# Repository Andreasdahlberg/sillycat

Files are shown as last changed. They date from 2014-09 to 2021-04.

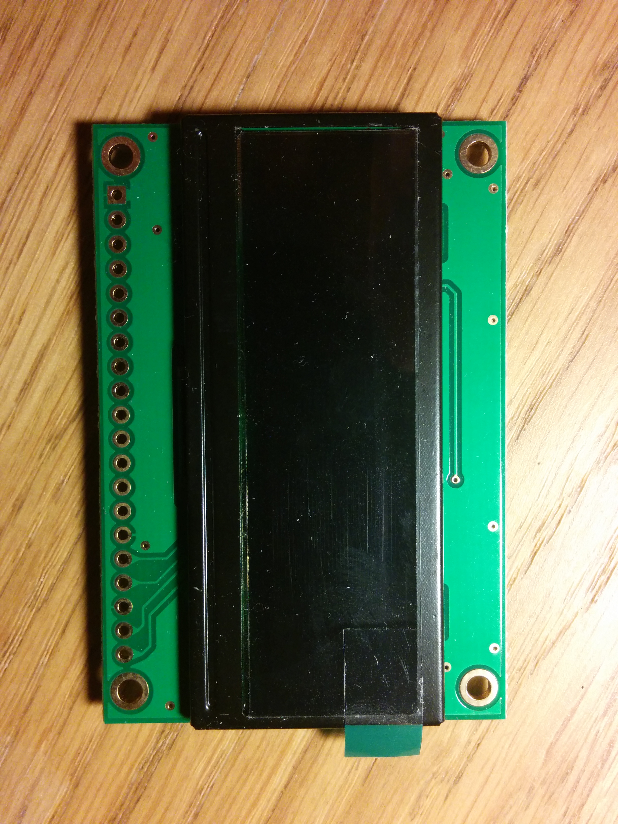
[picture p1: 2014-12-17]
hardware/main_unit_exterior/electrical_components/IMG_20141217_185025.jpg

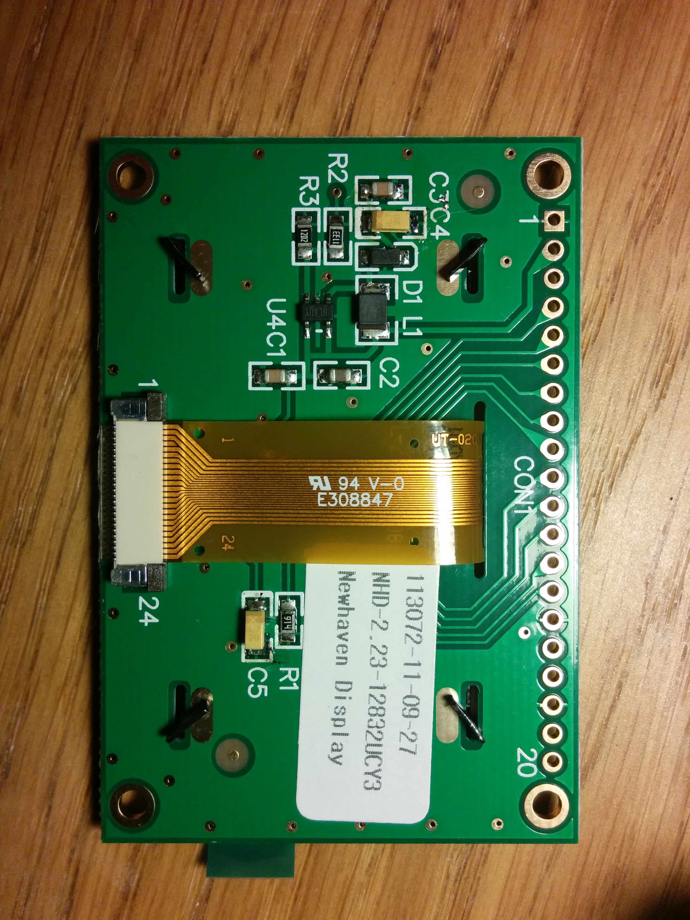
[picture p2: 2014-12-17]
hardware/main_unit_exterior/electrical_components/IMG_20141217_183510.jpg

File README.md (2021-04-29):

SillyCat
========




## Development

### Getting Started
The following steps are required

1. Install required packages
    ```bash
    $ sudo apt install scons gcc-avr avr-libc avrdude
    ```

1. Install optional packages
    ```bash
    $ sudo apt install astyle valgrind
    ```

1. Install [cmocka](https://cmocka.org/)
    ```bash
    $ sudo apt install cmake
    $ git clone git://git.cryptomilk.org/projects/cmocka.git
    $ mkdir cmocka/build && cd cmocka/build
    $ cmake -DCMAKE_INSTALL_PREFIX=/usr ..
    $ make
    $ sudo make install
    ```

1. Install [freetype-py](https://pypi.org/project/freetype-py/)
    ```bash
    $ sudo apt install python3-setuptools
    $ git clone https://github.com/rougier/freetype-py.git freetype-py
    $ cd freetype-py
    $ sudo python3 setup.py install
    ```

### Building
```bash
$ cd firmware
$ scons build-main-release build-node-release
```

### Board bringup
1. Set fuses
    ```bash
    $ scons init-fuses
    ```

1. Get configuration
    ```bash
    $ scripts/memory/config.py load /dev/ttyACM0 conf.eep
    ```

1. Set configuration values
    ```bash
    $ scripts/memory/config.py set conf.eep version 1
    $ scripts/memory/config.py set conf.eep network_id AABBCCDDEEFF
    $ scripts/memory/config.py set conf.eep aes_key 1DUMMYKEYFOOBAR1
    $ scripts/memory/config.py set conf.eep master_address 170
    $ scripts/memory/config.py set conf.eep address 170
    $ scripts/memory/config.py set conf.eep broadcast_address 255
    $ scripts/memory/config.py set conf.eep report_interval 60
    ```
    
    See [Configuration](scripts/memory/README.md#config) for details.

1. Save configuration to device
    ```bash
    $ /config.py save /dev/ttyACM0 conf.eep
    ```

1. Flash firmware
    ```bash
    scons flash-main-release
    ```   

### Testing
See [Testing](firmware/tests/README.md)

### CI
See [Docker](docker/README.md)

## Support
If you're having any problems, please raise an issue on GitHub and i will be happy to help.

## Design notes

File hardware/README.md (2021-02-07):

# Hardware description

## Main Unit

### BOM
| Qty | Line Item | Manufacturer | MPN | Octopart URL | Schematic Reference |
|-----|---|---|---|---|---|
| 1 | RFM69HW-868S2 | HOPERF | RFM69HW-868S2 | https://octopart.com/rfm69hw-868s2-hoperf-95997182 | U3 |
| 1 | 105133-0001 | Molex | 105133-0001 | https://octopart.com/105133-0001-molex-22605641 | U7 |
| 1 | NHD-2.23-12832UCY3 | Newhaven Display | NHD-2.23-12832UCY3 | https://octopart.com/nhd-2.23-12832ucy3-newhaven+display-20012478 | N/A |
| 1 | ATMEGA328P-AUR | Microchip | ATMEGA328P-AUR | https://octopart.com/atmega328p-aur-microchip-77760216 | U1 |
| 1 | CL21A106KPFNNNG | Samsung | CL21A106KPFNNNG | https://octopart.com/cl21a106kpfnnng-samsung-21703273 | C15 |
| 1 | CL21B103KAANNNC | Samsung | CL21B103KAANNNC | https://octopart.com/cl21b103kaannnc-samsung-19832247 | C4 |
| 5 | CL21B104KACNNNC | Samsung | CL21B104KACNNNC | https://octopart.com/cl21b104kacnnnc-samsung-19832262 | C1,C2,C7,C10,C12 |
| 6 | CL21B105KAFNNNE | Samsung | CL21B105KAFNNNE | https://octopart.com/cl21b105kafnnne-samsung-9301147 | C6,C8,C9,C11,C13,C14 |
| 1 | LD1117V33 | STMicroelectronics | LD1117V33 | https://octopart.com/ld1117v33-stmicroelectronics-526800 | U8 |
| 3 | RC2012J101CS | Samsung | RC2012J101CS | https://octopart.com/rc2012j101cs-samsung-63172 | R2,R3,R5 |
| 1 | RC2012F472CS | Samsung | RC2012F472CS | https://octopart.com/rc2012f472cs-samsung-26451238 | R1 |
| 1 | 22284200 | Molex | 22284200 | https://octopart.com/0022284200-molex-17769515 | U2 |
| 1 | 61200621621 | Würth Elektronik | 61200621621 | https://octopart.com/61200621621-w%C3%BCrth+elektronik-32855456 | U11 |
| 1 | BH32T-C | Memory Protection Devices | BH32T-C | https://octopart.com/bh32t-c-memory+protection+devices-30310562 | U5 |
| 10  | RC2012F103CS | Samsung | RC2012F103CS | https://octopart.com/rc2012f103cs-samsung-22085131 | R4,R6,R7,R8,R9,R10,R11,R12,R13,R14 |
| 1 | 22284040 | Molex | 22-28-4040 | https://octopart.com/22-28-4040-molex-278172 | J1,J4 |
| 1 | DS3234S# | Maxim Integrated | DS3234S# | https://octopart.com/ds3234s%23-maxim+integrated-8045298 | U9 |
| 1 | U.FL-R-SMT-1(40) | Hirose | U.FL-R-SMT-1(40) | https://octopart.com/u.fl-r-smt-1%2840%29-hirose-25525713 | J5 |

## Links
[Octopart BOM](https://octopart.com/bom-tool/Nu0NE4Zn)

[OSHPark PCB](https://oshpark.com/shared_projects/RTkTkiwv)

## Node Unit

## Gerbers
[NI Ultiboard](https://en.wikipedia.org/wiki/NI_Ultiboard) is used to generate the gerber files.

1. [Remove alignment points](https://docs.oshpark.com/design-tools/ni-ultiboard/removing-alignment-points/)
1. Click on File->Export and select the *Exports* tab
1. Check the Gerber RS-274X option and select the following layers:
	* Copper(all)
	* Board Outline
	* Silkscreen Top
	* Silkscreen Bottom
	* Solder Mask Top
	* Solder Mask Bottom
	* Drill(all)
1. Check the NC drill and select the following options:
	* Imperial
	* Coordinate format 2.4

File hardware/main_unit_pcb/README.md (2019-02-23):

# Main PCB

## Links
[BOM](https://octopart.com/bom-tool/QjR0VuVt)

[Order Rev1 PCB](https://oshpark.com/shared_projects/RTkTkiwv)

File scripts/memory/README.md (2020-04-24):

# Memory helper scripts

## Reader
Reader is a script for reading and printing device error logs. This can be done
directly from the device by dumping the EEPROM or by reading the EEPROM content
from a HEX-file.

### Usage
Read error log from device:
```bash
$ ./reader.py port <PORT>
```

Read error log from file:
```bash
$ ./reader.py file <FILENAME>
```

## Config
Config is a script used for configuration of both node and main devices.

### Usage
Load the configuration from the device into a configuration file:
```bash
$ ./config.py load <PORT> <FILENAME>
```

Print configuration values from the supplied configuration file:
```bash
$ ./config.py get <FILENAME> version address
version=1
address=170
```

Set a configuration value in the configuration file:
```bash
$ ./config.py set <FILENAME> address 128
```

Save the configuration file to device:
```bash
$ ./config.py save <PORT> <FILENAME>
```

## Hardware Requirements
When dumping the EEPROM from device an AVR programmer such as
[Olimex AVR-ISP-MK2](https://www.olimex.com/Products/AVR/Programmers/AVR-ISP-MK2/open-source-hardware)
is needed.

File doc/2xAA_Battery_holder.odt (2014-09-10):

PCB direct mounting AA battery holders

Description

A neat 2 x AA battery holder which can mount directly onto a PCB, thus saving ugly wiring and mounting problems.

Specifications

Dimensions: 57 mm x 33 mm x 15 mm

Battery: 2 x AA batteries

Connections: PCB pins on base (12 mm between pins)

Color: Black

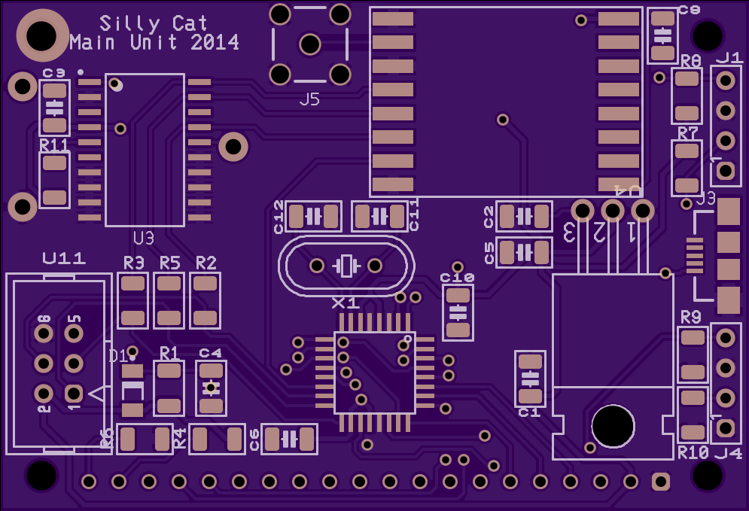
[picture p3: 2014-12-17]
hardware/main_unit_exterior/pcb_top.png

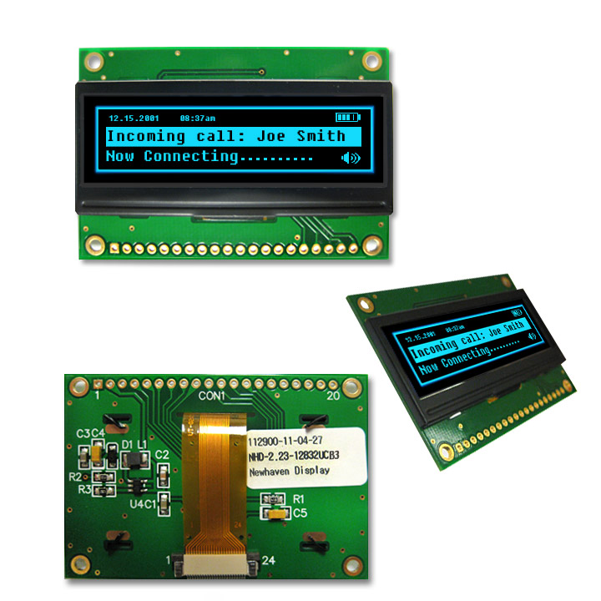
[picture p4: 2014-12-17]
hardware/main_unit_exterior/display.jpg

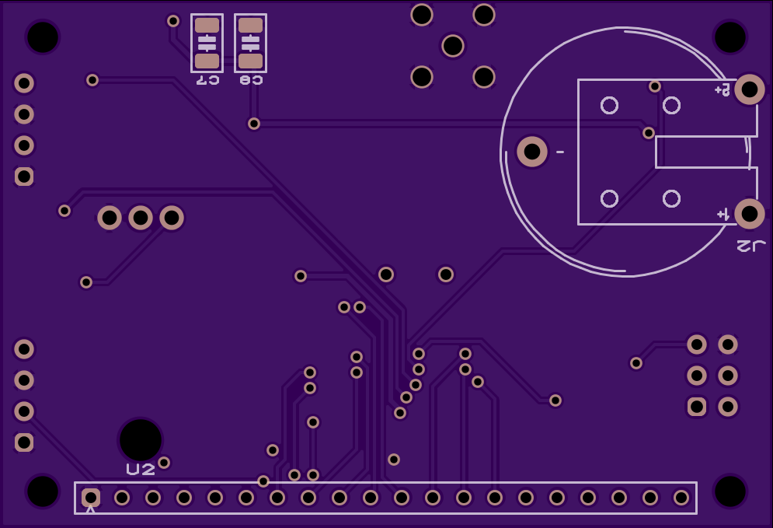
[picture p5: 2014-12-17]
hardware/main_unit_exterior/pcb_bottom.png

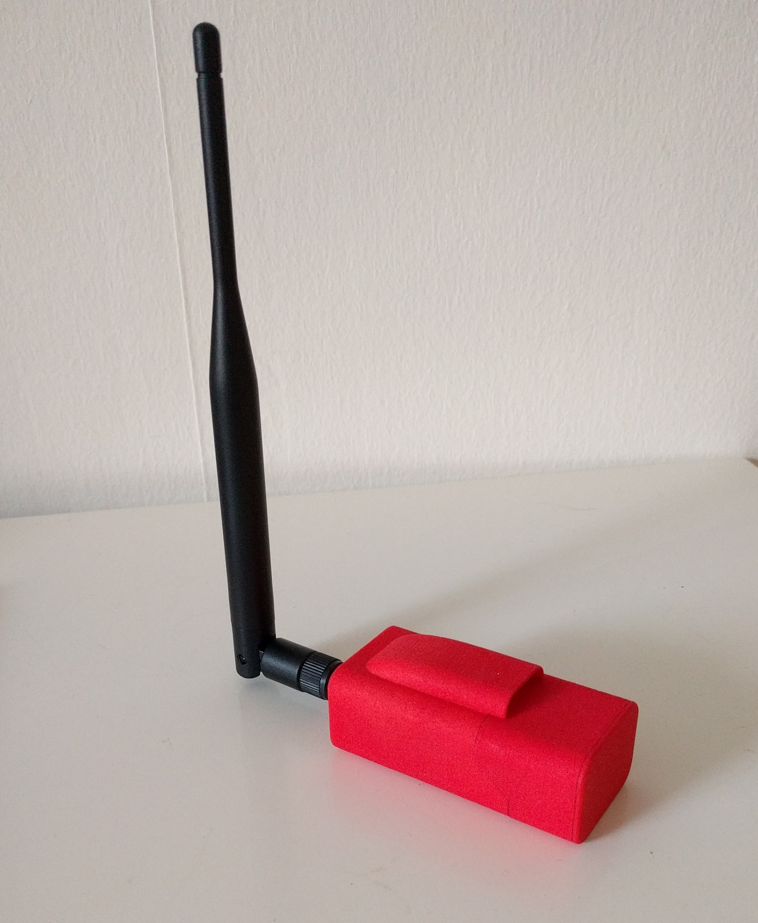
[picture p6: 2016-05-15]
doc/images/red_node.jpg

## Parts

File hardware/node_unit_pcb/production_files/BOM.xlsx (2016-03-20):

Quantity | Description | RefDes | Package | Type | Obsolete | Vendor | Status | Price | Hyperlink | Manufacturer | Manufacturer Part No. | Vendor Part No.
1 | INDUCTOR, 10µH 20% | L1 | IPC-7351\Chip-R1812 |  | - | Digi-Key |  | 4.11 | http://www.digikey.se/product-detail/en/murata-electronics-north-america/LQH43CN100K03L/490-2519-2-ND/599911 | Murata | LQH43CN100K03L | 490-2519-2-ND
1 | Buck_Boost, LTC3531-3.3 | U16 | Ultiboard\TSOT-23 |  | No | Digi-Key |  | 41,03 | http://www.linear.com/product/LTC3531 | Linear Technology | LTC3531ES6-3.3#TRMPBF | LTC3531ES6-3.3#TRMPBFCT-ND
2 | CAPACITOR, 10µF 10% | C5, C7 | Ultiboard\C0805S | Ceramic X5R | - | Digi-Key |  | 3,38 | http://www.digikey.se/product-detail/en/GRM219R61A106KE44D/490-4735-1-ND/1244331 | Murata Electronics North America | GRM219R61A106KE44D | 490-4735-1-ND
1 | PWR, LTC4060EFE | U2 | Ultiboard\TSSOP-16 |  | No | Digi-Key |  | 65,94 | http://www.linear.com/product/LTC4060 | Linear Technology | LTC4060EFE | LTC4060EFE#PBF-ND
1 | RESISTOR, 1.5KΩ 1% | R8 | Ultiboard\R0805S | Metal Film | - | Digi-Key |  | 1,01 | http://www.digikey.se/product-detail/en/RR1220P-152-D/RR12P1.5KDCT-ND/432834 | Susumu | RR1220P-152-D | RR12P1.5KDCT-ND
1 | CAPACITOR, 1100pF 5% | C1 | Ultiboard\C0805S | Ceramic | - | Digi-Key |  | 1,6 | http://www.digikey.se/product-detail/en/GRM2165C1H112JA01D/490-1623-1-ND/587523 | Murata Electronics North America | GRM2165C1H112JA01D | 490-1623-1-ND
1 | CAPACITOR, 10µF 5% | C2 | Ultiboard\C0805S | Ceramic | - | Digi-Key |  | 3,38 | http://www.digikey.se/product-detail/en/GRM219R61A106KE44D/490-4735-1-ND/1244331 | Murata Electronics North America | GRM219R61A106KE44D | 490-4735-1-ND
1 | Resistors, MF52 | U15 | Ultiboard\smd_temp_connector |  | No | Digi-Key |  | 4,06 | http://www.digikey.se/product-detail/en/MF52A2103J3470/317-1258-ND/1191033 | Cantherm | MF52A2103J3470 | 317-1258-ND
1 | RESISTOR, 3.9kΩ 1% | R9 | Ultiboard\R1206S | Metal Film | - | Digi-Key |  | 1,01 | http://www.digikey.se/product-detail/en/RR1220P-392-D/RR12P3.9KDCT-ND/432844 | Susumu | RR1220P-392-D | RR12P3.9KDCT-ND
1 | MOSFET_P, FDG312P | U14 | Analog Devices\SC70-6(KS-6) |  | No | Digi-Key |  | 4,33 | http://www.digikey.se/product-detail/en/FDG312P/FDG312PCT-ND/3042786 | Fairchild Semiconductor | FDG312P | FDG312PCT-ND
1 | Schottky, SD0805S020S1R0 | U13 | IPC-7351\Chip-C0805 |  | No | Digi-Key |  | 3,56 | http://www.digikey.se/product-detail/en/SD0805S020S1R0/478-7800-1-ND/3749510 | AVX Corporation | SD0805S020S1R0 | 478-7800-1-ND
2 | thermal, V5618A | U17, U18 | Ultiboard\Heatsink-V5618A |  | No | Digi-Key |  | 5,63 | http://www.digikey.se/product-detail/en/V5618A/AE10819-ND/3511413 | Assmann WSW Components | V5618A | AE10819-ND
2 | RESISTOR, 0.1Ω 1% | R13, R14 | Ultiboard\R0805S |  | -
2 | MOSFET_P, 2SB1182 | U12, U24 | International Rectifier\TO-252AA(DPAK) |  | No | Digi-Key |  | 9,04 | http://www.digikey.se/product-detail/en/2SB1182TLQ/2SB1182TLQCT-ND/1158546 | Rohm Semiconductor | 2SB1182TLQ | 2SB1182TLQCT-ND
1 | RTC, MCP79510 | U3 | Linear Technology\MSOP-10(MS) |  | No | Digi-Key |  | 11,92 | http://www.microchip.com/wwwproducts/Devices.aspx?product=MCP79510 | Microchip Technology | MCP79510-I/MS | MCP79510-I/MS-ND
2 | CAPACITOR, 18pF 5% | C3, C8 | Ultiboard\C0805S | Ceramic | - | Digi-Key |  | 0,92 | http://www.digikey.se/product-detail/en/CL21C180JBANNNC/1276-1107-1-ND/3889193 | Samsung Electro-Mechanics America, Inc | CL21C180JBANNNC | 1276-1107-1-ND
4 | RESISTOR, 10kΩ 1% | R6, R10, R12, R15 | Ultiboard\R0805S | Metal Film | - | Digi-key |  | 2,67 | http://www.digikey.se/product-detail/en/RPC0805JT10K0/RPC0805JT10K0CT-ND/3043921 | Stackpole Electronics Inc | RPC0805JT10K0 | RPC0805JT10K0CT-ND
1 | CRY, R26-32.768kHz | X2 | Ultiboard\MC-306 |  | No | Digi-Key |  | 5,432 | http://www.digikey.se/product-detail/en/MC-306%2032.768K-E3:ROHS/SER2417TR-ND/1022179 | EPSON | MC-306 32.768K-E3:ROHS | SER2417TR-ND
1 | RF_COAXIAL, 73391-0060 | J5 | Molex\73391-0060 |  | No |  |  |  |  | Molex
1 | wireless, RFM69HW_1 | U5 | Ultiboard\rfm69hw |  | No | TME |  | 40,88 | http://www.hoperf.com/rf/fsk_module/RFM69HW.htm | HOPE MICROELECTRONICS | RFM69W-868S2 | RFM69W-868S2
2 | CAPACITOR, 0.1µF 5% | C16, C17 | Ultiboard\C0805S | Ceramic | - | Digi-Key |  | 1,07 | http://www.digikey.se/product-detail/en/C2012X5R1H104K085AA/445-14401-1-ND/3956067 | TDK Corporation | C2012X5R1H104K085AA | 445-14401-1-ND
2 | Capacitors, 1uF_5% | U6, U8 | Ultiboard\C0805S |  | No | Digi-Key |  | 2,31 | http://www.digikey.se/product-detail/en/C2012X5R1H105K085AB/445-10547-1-ND/3947716 | TDK Corporation | C2012X5R1H105K085AB | 445-10547-1-ND
1 | RESISTOR, 5.6KΩ 0.5% | R4 | Ultiboard\R0805S | Thin film | - | Digi-Key |  | 1,01 | http://www.digikey.se/product-detail/en/RR1220P-562-D/RR12P5.6KDCT-ND/432848 | Susumu | RR1220P-562-D | RR12P5.6KDCT-ND
1 | RESISTOR, 100KΩ 1% | R7 | Ultiboard\R0805S | Metal Film | - | Digi-Key |  | 1,01 | http://www.digikey.se/product-detail/en/RR1220P-104-D/RR12P100KDCT-ND/432878 | Susumu | RR1220P-104-D | RR12P100KDCT-ND
1 | POWER, 2462 | J1 | Ultiboard\battery_holder |  | No | Ebay |  | 48,93 | http://www.ebay.com/itm/271598083869
1 | UC, ATmega328P-32 | U1 | Ultiboard\TQFP-32-7mm |  | No | Digi-Key |  | 34,13 | http://www.atmel.com/devices/atmega328p.aspx | Atmel | ATMEGA328P-AUR | ATMEGA328P-AURCT-ND
1 | Sensors, RHT03 | U4 | Ultiboard\wago-2059-303 |  | No | Sparkfun |  | 96,00 | https://www.sparkfun.com/products/10167 | Maxdetect | RHT03 | RHT03
1 | CAPACITOR, 10nF 5% | C4 | Ultiboard\C0805S | Ceramic | - | Digi-Key |  | 2,21 | http://www.digikey.se/product-detail/en/C0805C103K4RACTU/399-7995-1-ND/3471718 | Kemet | C0805C103K4RACTU | 399-7995-1-ND
4 | RESISTOR, 4.7kΩ 1% | R1, R2, R3, R5 | Ultiboard\R0805S | Metal Film | - | Digi-Key |  | 2,77 | http://www.digikey.se/product-detail/en/PCR0805-4K7J1/696-1387-1-ND/3507345 | Riedon | PCR0805-4K7J1 | 696-1387-1-ND
1 | USB, 10104111-0001LF | J3 | Ultiboard\usb_no_silk |  | No | Digi-Jey |  | 4,43 | http://www.digikey.se/product-detail/en/10118192-0001LF/609-4613-1-ND/2785378 | FCI | 10118192-0001LF | 609-4613-1-ND
3 | Capacitors, 0.1uF_5% | U9, U19, U20 | Ultiboard\C0805S |  | No | Digi-Key |  | 1,07 | http://www.digikey.se/product-detail/en/C2012X5R1H104K085AA/445-14401-1-ND/3956067 | TDK Corporation | C2012X5R1H104K085AA | 445-14401-1-ND
1 | leds, WL-SWTP | U21 | Ultiboard\led1206 |  | No | Digi-Key |  | 4,33 | http://www.digikey.se/product-detail/en/158301250/732-5661-1-ND/4947879 | Wurth Electronics Inc | 158301250 | 732-5661-1-ND
1 | RESISTOR, 100Ω | R11 | Ultiboard\R0805S |  | - | Digi-key |  | 0,82 | http://www.digikey.se/product-detail/en/CRCW0805100RFKEA/541-100CCT-ND/1180669 | Vishay Dale | CRCW0805100RFKEA | 541-100CCT-ND
1 | memory, S25FL032P | U23 | Ultiboard\S25FL164K |  | No | Digi-key |  | 10,15 | http://www.digikey.se/product-detail/en/S25FL032P0XMFI013/1274-1170-1-ND/5222356 | Spansion | S25FL032P0XMFI013 | 1274-1170-1-ND
1 | headers, Pogo-connector | U10 | Ultiboard\pogo_connector_female_2 |  | No

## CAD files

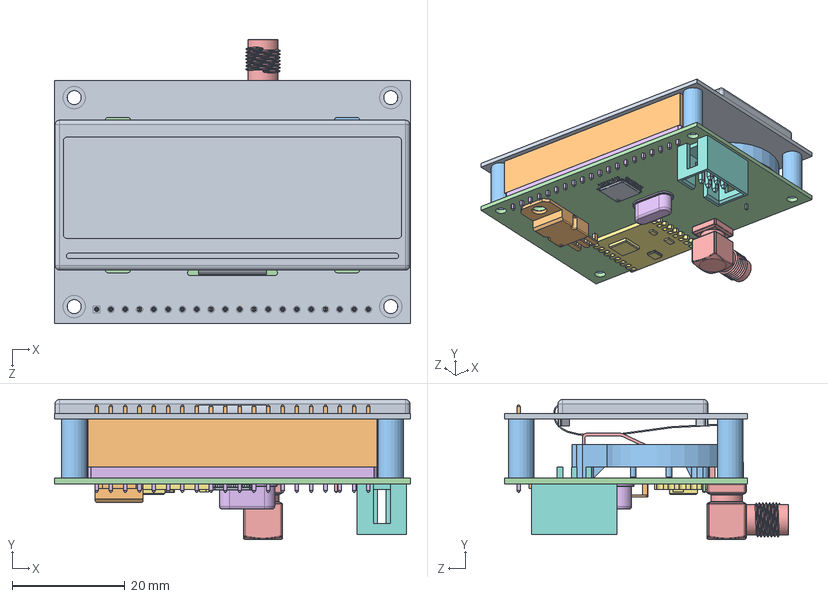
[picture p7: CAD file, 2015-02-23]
hardware/main_unit_exterior/main_unit_assembly.SLDASM
63.2 x 24.9 x 50.4 mm
NHD_223_OLED_display
female_header_20
pcb_spacer x 4
main_pcb
SMA-angled
male_header_20
rfm69hw
isp_header_6pin
TQFP-32
TO-220
C2023_battery_holder_body
C2023_battery_holder_bottom_spring
C2023_battery_holder_top_spring
H49_crystal_low

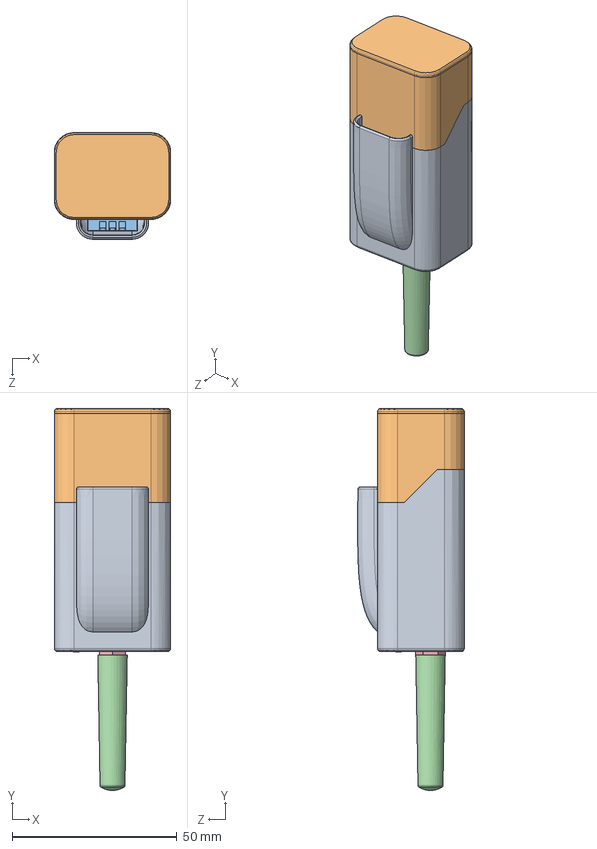
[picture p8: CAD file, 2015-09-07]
hardware/node_unit_exterior/node_assembly.SLDASM
35.4 x 116.1 x 32.4 mm
casing_lower
casing_upper
dht11_body
dht11_pcb
led_diffuser
pcb
rfm69hw
SMA-angled
TQFP-32
micro usb
micro usb02
battery_holder_body
end_plug
end_plug_pin
spring
spring_pin
aa_battery x 2
resistor_1206 x 10
cap1206 x 12
1206_led_blue
end_cover_usb
heatsink_V5618A x 2
wago_2059_303_casing
wago_2059_303_pin x 3
DPAK
end_plug_cover
nfc_tag
SMA_antenna
SMA_nut

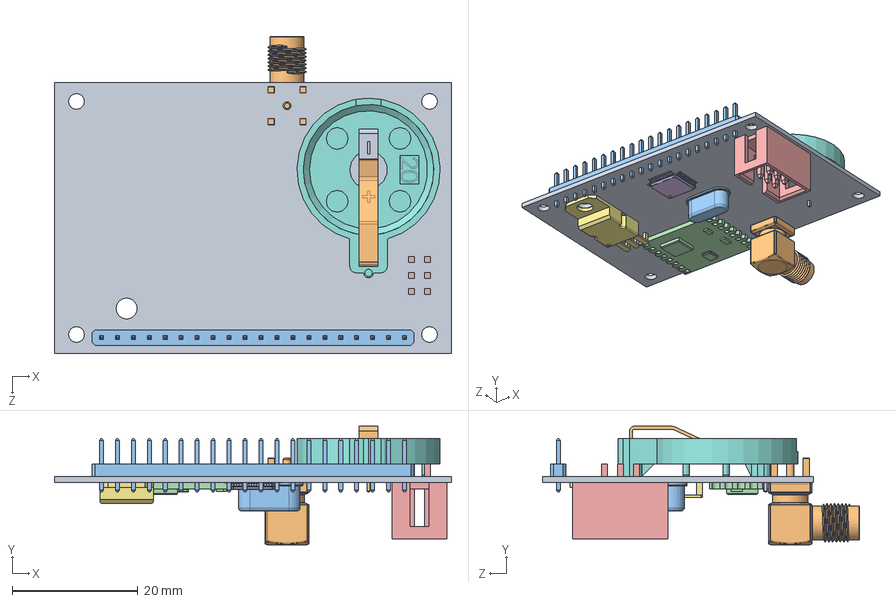
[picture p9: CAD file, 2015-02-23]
hardware/main_unit_exterior/main_pcb_assembly.SLDASM
63.2 x 18.9 x 50.4 mm
main_pcb
SMA-angled
male_header_20
rfm69hw
isp_header_6pin
TQFP-32
TO-220
C2023_battery_holder_body
C2023_battery_holder_bottom_spring
C2023_battery_holder_top_spring
H49_crystal_low

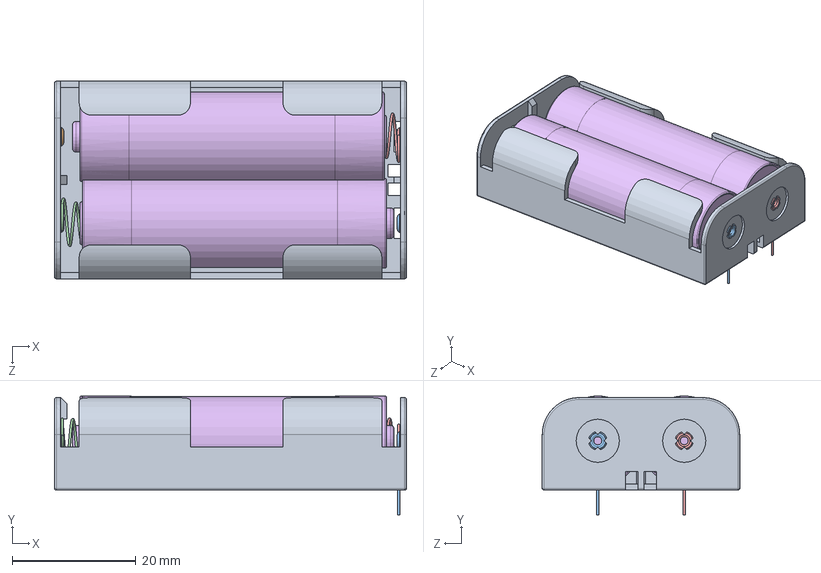
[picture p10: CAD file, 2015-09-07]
hardware/node_unit_exterior/battery_assembly.SLDASM
57.0 x 19.3 x 32.0 mm
battery_holder_body
end_plug
end_plug_pin
spring
spring_pin
aa_battery x 2

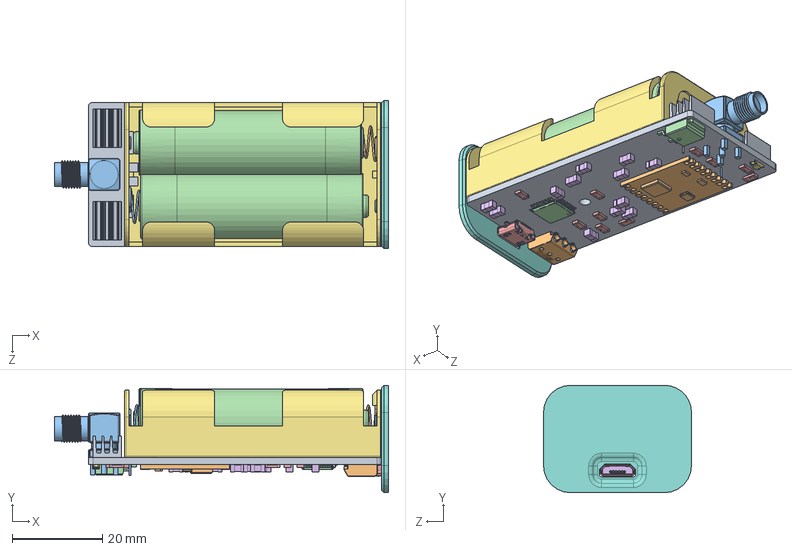
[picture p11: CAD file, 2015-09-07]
hardware/node_unit_exterior/pcb_assembly.SLDASM
74.0 x 23.8 x 32.8 mm
pcb
rfm69hw
SMA-angled
TQFP-32
micro usb
micro usb02
battery_holder_body
end_plug
end_plug_pin
spring
spring_pin
aa_battery x 2
resistor_1206 x 10
cap1206 x 12
1206_led_blue
end_cover_usb
heatsink_V5618A x 2
wago_2059_303_casing
wago_2059_303_pin x 3
DPAK

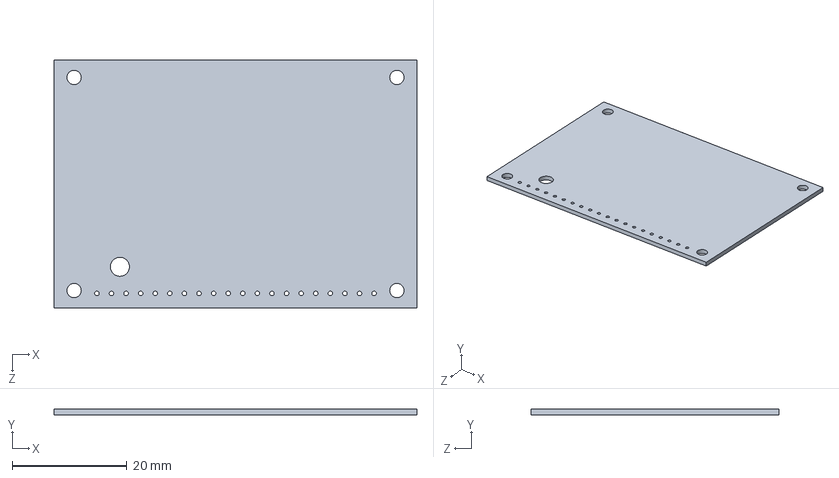
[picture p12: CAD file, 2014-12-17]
hardware/main_unit_exterior/electrical_components/main_pcb.SLDPRT
63.2 x 1.00 x 43.1 mm

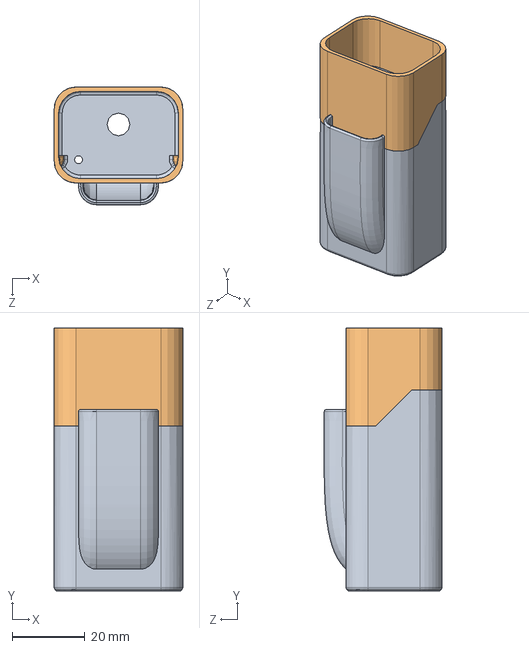
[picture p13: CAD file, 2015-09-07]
hardware/node_unit_exterior/casing_assembly.SLDASM
35.4 x 72.4 x 32.4 mm
casing_lower
casing_upper

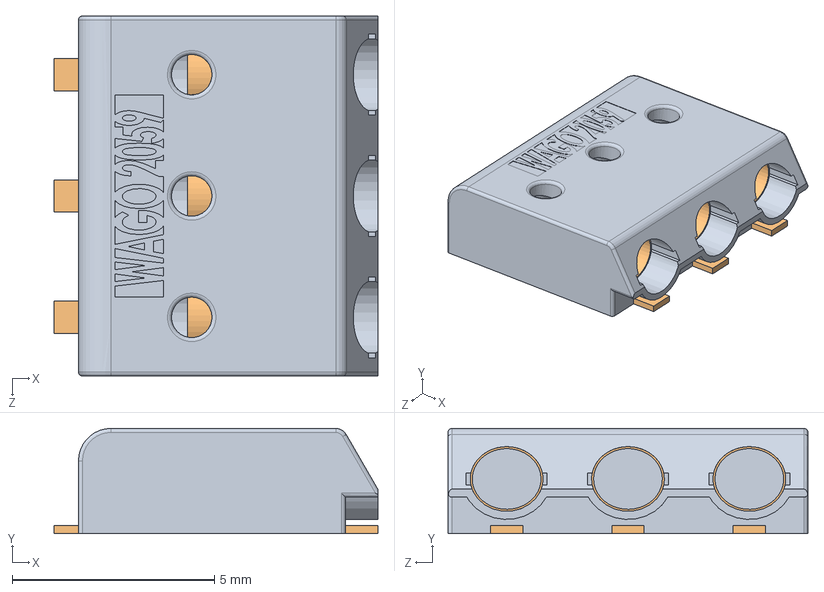
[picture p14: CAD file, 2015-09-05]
hardware/node_unit_exterior/standard_components/wago_2059_303.SLDPRT.SLDASM
8.00 x 2.60 x 8.90 mm
wago_2059_303_casing
wago_2059_303_pin x 3

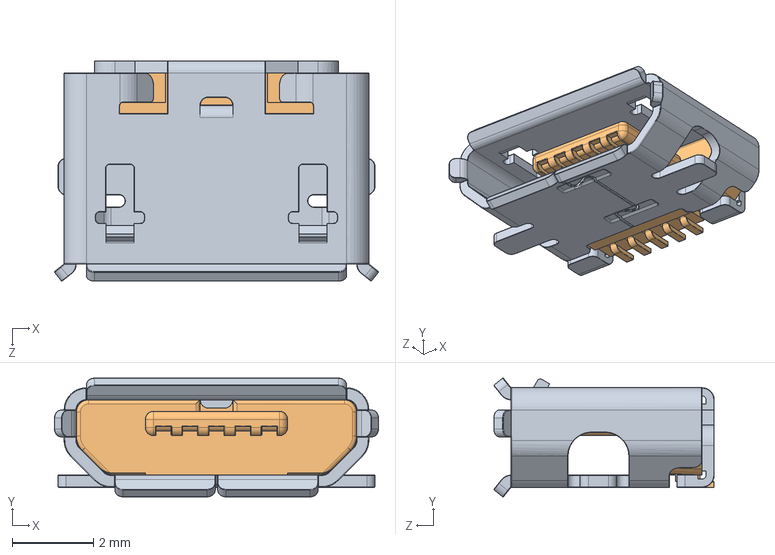
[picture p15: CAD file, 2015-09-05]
hardware/node_unit_exterior/standard_components/micro USB.SLDASM
7.97 x 2.92 x 5.43 mm
micro usb
micro usb02

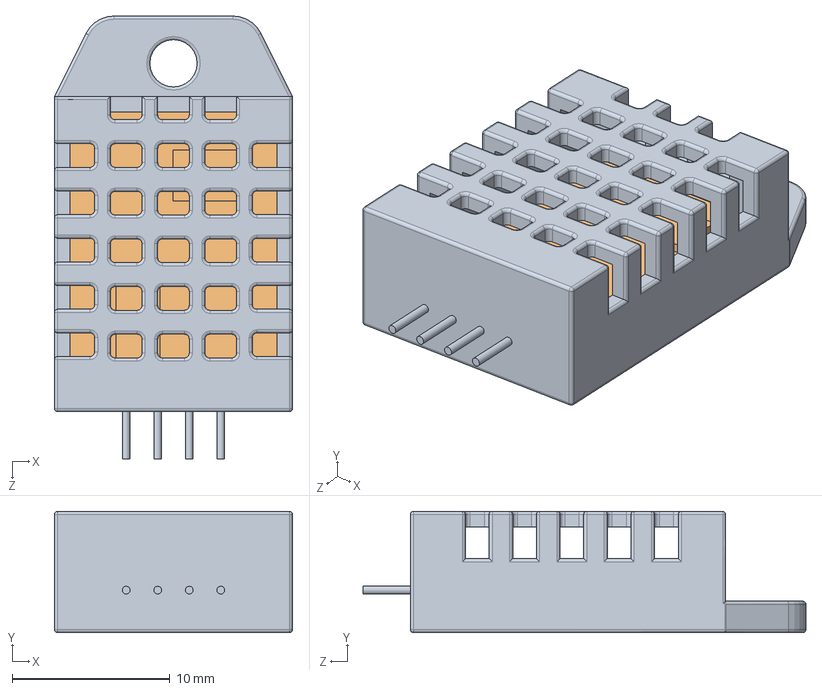
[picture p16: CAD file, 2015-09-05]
hardware/node_unit_exterior/dht_assembly.SLDASM
15.1 x 7.70 x 28.1 mm
dht11_body
dht11_pcb

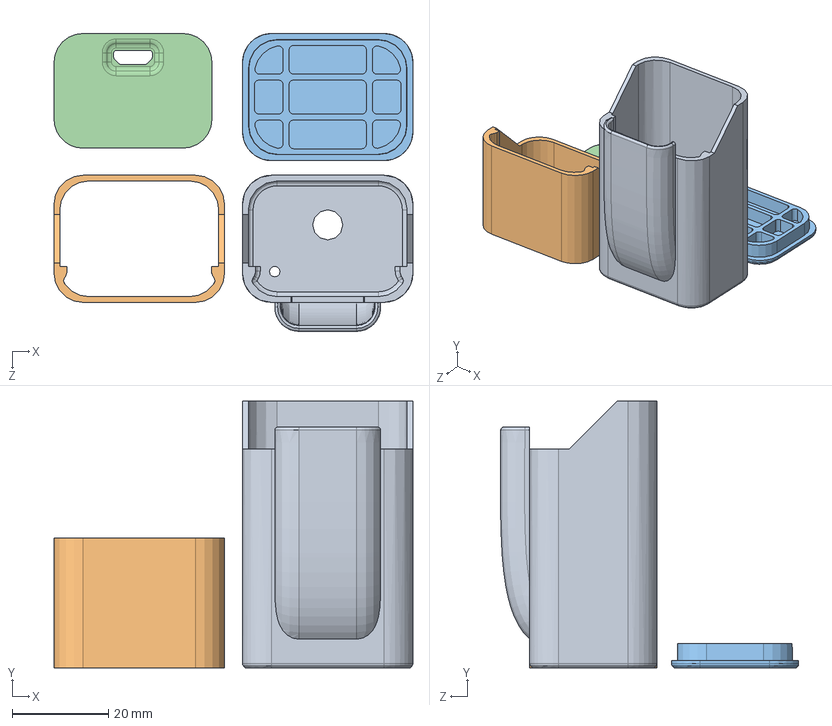
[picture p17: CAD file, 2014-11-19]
hardware/node_unit_exterior/casing_3d_printer_ready.SLDASM
74.5 x 55.4 x 61.9 mm
casing_lower
casing_upper
end_plug_cover
end_cover_usb

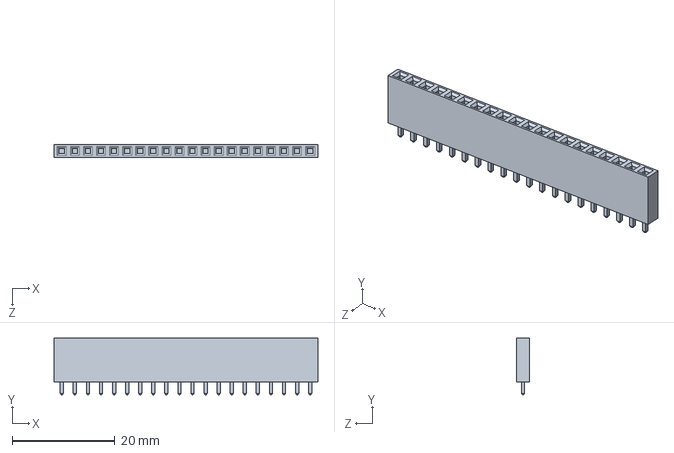
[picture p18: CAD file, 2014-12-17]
hardware/main_unit_exterior/electrical_components/female_header_20.SLDPRT
51.3 x 11.0 x 2.50 mm

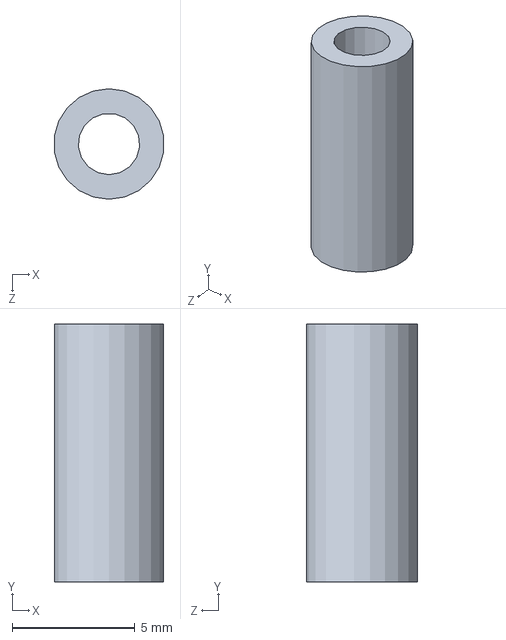
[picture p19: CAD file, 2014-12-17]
hardware/main_unit_exterior/mechanical_components/pcb_spacer.SLDPRT
4.45 x 10.5 x 4.50 mm

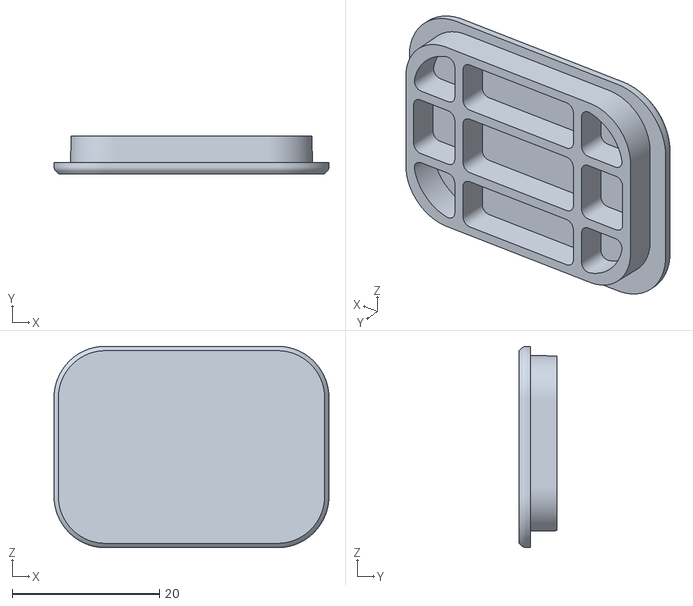
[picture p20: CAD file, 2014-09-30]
hardware/node_unit_exterior/production_files/casing_end_cover.STL
37.4 x 5.10 x 27.4

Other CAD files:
hardware/node_unit_exterior/standard_components/aa_battery.SLDPRT
hardware/main_unit_exterior/electrical_components/male_header_20.SLDPRT
hardware/main_unit_exterior/mechanical_components/front_casing.SLDPRT
hardware/node_unit_exterior/production_files/casing_end_cover_usb.STL
hardware/main_unit_exterior/electrical_components/NHD_223_OLED_display.SLDPRT
hardware/main_unit_exterior/electrical_components/TO-220.SLDPRT
hardware/node_unit_exterior/casing_lower.SLDPRT
hardware/node_unit_exterior/casing_upper.SLDPRT
hardware/node_unit_exterior/dht11_body.SLDPRT
hardware/node_unit_exterior/dht11_pcb.SLDPRT
hardware/node_unit_exterior/end_cover_usb.SLDPRT
hardware/node_unit_exterior/end_plug_cover.SLDPRT
hardware/node_unit_exterior/led_diffuser.SLDPRT
hardware/node_unit_exterior/pcb.SLDPRT
hardware/node_unit_exterior/production_files/casing_casing_upper.STL
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

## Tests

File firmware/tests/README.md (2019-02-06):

# Testing

[Cmocka](https://cmocka.org/) is used as the unit testing framework for firmware.

## Build test suites
Use the following command to build all test suites:
```bash
$ scons build-tests
```

It's also possible to build a specific test suite, e.g. the timer test suite:
```bash
$ scons tests/common/timer/
```

## Run test suites
Run all test suites:
```bash
$ scons coverage
```

Run a specific test suite, e.g. the timer test suite.
```bash
$ build/unit_tests/timer/TestRunner
```

## Add a new test suite
1. Add a new directory for the test suite in *tests*. It's important that the
directory structure is the same as in the *src* directory. Assume we want to
add a test suite for the *src/main/encoder* module, then we create
*tests/main/encoder*.

1. Create a SConscript file with the following content
    ```python
    import os

    Import(['*'])

    env.Append(CPPPATH=[
        '<PATH_TO_INCLUDE>'
    ])

    env.Append(LINKFLAGS=[
        '-Wl,--wrap=<FUNCTION_TO_MOCK>'
    ])

    SOURCE = Glob('*.c')
    OBJECTS = env.Object(source=SOURCE)

    Return('OBJECTS')
    ```
1. Implement the test suite in *test_MODULE_NAME.c*. A basic template is
included below but the existing test suites is the best place to learn how to write tests.
    ```c
    #include <stdarg.h>
    #include <stddef.h>
    #include <setjmp.h>
    #include <cmocka.h>

    void test_SomeImportantTest(void **state)
    {
        /* Implement test case here. */
    }

    int main(void)
    {
        const struct CMUnitTest tests[] =
        {
            cmocka_unit_test(test_SomeImportantTest)
        };
        return cmocka_run_group_tests(tests, NULL, NULL);
    }
    ```
1. Enable the test by adding the full module path to the *modules* list in the
*SConstruct* file.
    ```python
    modules = [
        os.path.join('utility', 'CRC'),
        os.path.join('utility', 'List'),
        os.path.join('utility', 'FIFO'),
        os.path.join('main', 'encoder'),
        os.path.join('main', 'interface'),
        os.path.join('common', 'timer')
    ]
    ```
1. Thats all! You can now [build](#build-test-suites) and [run](#run-test-suites) your new test suite.

## GDB
If a test fails with segmentation fault [GDB](https://www.gnu.org/software/gdb/)
is a great tool to use to track down the fault.
```bash
$ gdb build/unit_tests/timer/TestRunner
```

This will load the test application into GDB and present the GDB console.

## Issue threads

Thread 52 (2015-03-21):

Crystal frequency too high

Andreasdahlberg, 2015-03-21:
A frequency of 20 MHz can only be used if VDD is >= 4.5 V. VDD is 3.3 so the max frequency is 16 MHz.  Change X1 to this value, should not affect the footprint.

Andreasdahlberg, 2018-08-30:
Use the internal RC oscillator instead. This frees up space in the middle of the PCB for the new vertical USB-connector. Two more IO-pins are also made available.

The prototype have been using the internal RC oscillator all the time and 8 MHz have been proven to be enough for updating the user interface fast enough.

Closed 2018-08-30.

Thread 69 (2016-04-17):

Remove R12 pull-up.

Andreasdahlberg, 2016-04-17:
Remove R12, using MCU pull-up instead.

R12 is a pull-upp resistor for the RTC MFP pin(used for wakeup signal).

Andreasdahlberg, 2017-11-19:
Decided to keep it. With the footprint in place i can decide if i should mount it or not.

Closed 2017-11-19.

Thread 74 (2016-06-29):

Intermittent reset during user input

Andreasdahlberg, 2016-06-29:
Intermittent reset(BoR, PoR) during user input. Caused by a short drop of the supply voltage.

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

Andreasdahlberg, 2016-06-30:
**Cause**: Short circuit between Vcc and GND in the rotary encoder when the push button was pressed to hard in some positions.

**Solution**: Change to a high quality rotary encoder. Mount a small value resistor(470 Ohm) between Vcc and the encoder to limit the current if a short circuit happens.

Andreasdahlberg, 2016-08-14:
Changed to [Bourns PEC11-encoder](https://www.bourns.com/data/global/pdfs/PEC11R.pdf) and mounted a current limiting resistor.

Closed 2016-08-14.

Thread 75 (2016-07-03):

Array index out of bound in libADC

Andreasdahlberg, 2016-07-03:
Out of bounds array index in libADC while scanning through channels.

`
            while (adc_inputs[current_input].active != true &&
                    current_input < MAX_ADC_INPUTS)
`
The two conditions above should change place to avoid this.

Closed 2016-07-03.

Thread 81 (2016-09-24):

Fix formatting rules for switch-cases.

Andreasdahlberg, 2016-09-24:
As title, formating for switch-cases are broken.

Closed 2016-09-24.

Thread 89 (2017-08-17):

Node device does not enter/exit sleep state

Andreasdahlberg, 2017-08-17:
In some rare cases the node device does not enter/exit the sleep state.

Andreasdahlberg, 2017-08-17:
The issue was caused by unreliable SPI communication with the RTC IC.
Fixed in 0229f2c0a4dc44e4525d348e2d10e94fd4b6b982.

Before hardware patch
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

After hardware patch
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

Closed 2017-08-17.

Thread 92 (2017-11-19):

False ERC warnings

Andreasdahlberg, 2017-11-19:
The electric rules check has some warnings(Connecting power to bidirectional) that probably are false warnings.

Find cause and fix.

Closed 2019-03-16.

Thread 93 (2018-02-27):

Invalid timestamp sent to node

Andreasdahlberg, 2018-02-27:
The node firmware does not perform any validation of received timestamps so invalid values such as 25 for hour is asserted in the RTC driver.

Log output:
`<ERROR> src/node/libMCP79510.c:293 (hour < 24)`

Cause: Main unit has no time set, caused by loss of RTC battery, this time is then sent to the node.

Fix: Validate the timestamp in the node firmware.

Closed 2018-03-26.

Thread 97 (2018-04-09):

Battery discharge protection

Andreasdahlberg, 2018-04-09:
To protect the battery when empty the nodes need to enter some sort of power-down mode and only wake-up when a charger is connected.

Closed 2018-04-11.

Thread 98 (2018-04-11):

Battery charging animation is too fast

Andreasdahlberg, 2018-04-11:
**Background**
According to user feedback the charging animation is to fast.

**Action**
Decrease the animation speed.

Closed 2018-04-20.

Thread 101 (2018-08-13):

Move USB-connector

Andreasdahlberg, 2018-08-13:
The USB-connector needs to be moved to fit into the casing. A vertical connector on the topside is an good option.

Andreasdahlberg, 2019-03-16:
Using a vertical connector in the middle of the PCB.

Closed 2019-03-16.

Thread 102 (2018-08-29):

Add input protection on PCB

Andreasdahlberg, 2018-08-29:
Add current limiting resistors for the rotary encoder inputs on the PCB to protect against short circuits in the encoder.

See #74 for root cause.

Closed 2019-02-21.

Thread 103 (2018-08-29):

Add filters on PCB for the rotary encoder

Andreasdahlberg, 2018-08-29:
The rotary encoder needs hardware filters to fix contact bouncing. Add these on the PCB.

Andreasdahlberg, 2019-02-21:
Fixed

Closed 2019-02-21.

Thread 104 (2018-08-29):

Pad on U4(LD1117V33) shorted to ground

Andreasdahlberg, 2018-08-29:
The pad on U4(LD1117V33) is connected to Vout internally, however on the PCB the thermal pad under the regulator is connected to ground causing an short circuit.

Andreasdahlberg, 2019-02-21:
Fixed

Closed 2019-02-21.

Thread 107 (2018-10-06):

Add master address to device configuration

Andreasdahlberg, 2018-10-06:
The master address is hard-coded now, add this parameter in the device configuration.

Andreasdahlberg, 2018-10-06:
Fixed in b2b1ed78394d9f1c790a2810e880d04cb1085fe3.

Closed 2018-10-06.

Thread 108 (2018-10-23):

Unstable subzero temperature readings

Andreasdahlberg, 2018-10-23:
The temperature readings seems very unstable when the temperature is below zero.

Andreasdahlberg, 2018-11-03:
Two possible workarounds:
* Add filtering capacitors
* Decrease α in software [filter](https://github.com/Andreasdahlberg/sillycat/blob/6f3256fdf1020c094b89e389dc0818bbc02a6b42/firmware/src/main/driver/NTC/driverNTC.c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)

Closed 2018-11-27.

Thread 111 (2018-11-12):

Replace DS3234 with MCP79510

Andreasdahlberg, 2018-11-12:
Replace DS3234 on the main unit with MCP79510, it's much easier to use the same RTC-IC on both devices.

Andreasdahlberg, 2019-02-21:
Fixed in 40cb38a9d406d5df285c62c5acdfa839ec9f1a06 and 3a3539fc718125b6fa46ba3ee112902d6e9b551e.

Closed 2019-02-21.

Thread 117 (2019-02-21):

Change to 4-layer board for the main PCB

Andreasdahlberg, 2019-02-21:
Change to 4-layer board for the main PCB to get better RF-performance.

Andreasdahlberg, 2019-03-04:
Fixed in 4f67aa22469b96de2d03fbf751d3e57336640a7e.

Closed 2019-03-04.

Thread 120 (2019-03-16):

Schematic and layout verification

Andreasdahlberg, 2019-03-16:
Run the ERC, DRC and connectivity check before release and make sure that no errors are present.

Closed 2019-09-21.

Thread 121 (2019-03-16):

Battery temperature measurements

Andreasdahlberg, 2019-03-16:
Connect the existing battery NTC to the MCU so that the MCU can measure the battery temperature.

The current implementation can't distinguish between overtemperature faults and end of charge.

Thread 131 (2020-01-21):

U7 is placed in the wrong direction

Andreasdahlberg, 2020-01-21:
U7(USB-connector) is placed in the wrong direction and does not match the cutout in the casing.

Andreasdahlberg, 2020-05-19:
Fixed in db8d9ed30be61d12e7a2144b79bf4f11f832d644

Closed 2020-05-19.

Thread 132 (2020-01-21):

Create board initialization script

Andreasdahlberg, 2020-01-21:
- Set fuses
- Clear errorlog
- Init config

Note: Remember to decrease ISP-speed until fuses are set.

Andreasdahlberg, 2021-03-21:
Use 'scons init-fuses ', see f77b4d05d47798a8061c40f42abf5cf220284167.

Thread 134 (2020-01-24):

Improve visibility of corrupt config

Andreasdahlberg, 2020-01-24:
When the config is corrupted the device halts with a black screen.

DoD:
Display some kind of error message.

Closed 2020-05-18.

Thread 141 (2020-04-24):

Replace antenna SMA connector with U.FL

Andreasdahlberg, 2020-04-24:
The SMA connector takes up to much space.

Remember to add the new connector and cable to the BOM.

Closed 2020-05-26.

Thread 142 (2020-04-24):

Move the ISP-connector towards the middle

Andreasdahlberg, 2020-04-24:
The ISP-connector needs to be moved since it's difficult to insert the ISP-cable when the PCB is mounted in the enclosure.

Closed 2020-05-26.

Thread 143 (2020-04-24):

RTC does not keep time and SRAM when powered down

Andreasdahlberg, 2020-04-24:
**Issue**
The RTC lose all SRAM-data and current time when the device is powered down.

**Solution**
Enable RTC VBAT switchover.

Closed 2020-04-24.

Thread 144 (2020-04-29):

Incorrect footprint for U5

Andreasdahlberg, 2020-04-29:
Change to correct footprint for U5(RTC battery holder) on main PCB.

Closed 2020-10-21.

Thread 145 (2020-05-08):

Very high RTC time drift

Andreasdahlberg, 2020-05-08:
The time drifts very much, at least 30 seconds in 1 hour is observed.

One possible cause is junk data in the MCP7951X CRSTRIM  and OSCTRIM registers. It can also be caused by an unreliable oscillator, the oscillator takes long time to start and the PCB layout is not optimal.

The next step should be to enable CLKOUT and measure the actual frequency.

**Firmware:** main-release 5e358d486d37cce05262bc22665892f7e8713e09
**Hardware:** Main board R2

Andreasdahlberg, 2020-05-11:
It's likely that the issue is caused by an unreliable oscillator since the crystal load capacitors(C3,C5) have way to high capacitance(18 pF).

(C1 * C2) / (C1 + C2) + Cstray = Cload
With Cload= 6 pF and assuming Cstray = 5 pF, the load capacitance should be 2 pF.

According to the [MCP7951X datasheet](http://ww1.microchip.com/downloads/en/DeviceDoc/MCP7951X-MCP7952X-Battery-Backed-SPI-RTCC-20002300C.pdf), table 1-1, the oscillator pin capacitance is 3 pF. This pin capacitance added to the trace capacitance( < 1 pF) should mean that the load capacitors could be removed.

Andreasdahlberg, 2020-05-15:
After clearing OSCTRIM the drift is severely reduced. However, it's still approximate 10 seconds after a couple of days.

Next step is to calculate the expected drift and compare with the real value. If worse then the expected value the load capacitance should be changed.

Another option for the next main board revision is to go back to using the [DS3234](https://www.maximintegrated.com/en/products/analog/real-time-clocks/DS3234.html). It's more expensive and takes up more PCB space but the easy of use and accuracy is probably worth it. The increased firmware complexity is negligible.

Andreasdahlberg, 2020-10-21:
Changed back to using DS3234 in c1e629f6f2c3a0a089277c7661e3dcece79dc7ff.

Closed 2020-10-21.

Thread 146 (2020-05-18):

GND via to close to R10

Andreasdahlberg, 2020-05-18:
A GND via is to close to one of the pads on R10 making it difficult to solder without shorting the pad to GND.

Closed 2020-05-19.

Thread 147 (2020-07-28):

Update Main Unit R3 BOM

Andreasdahlberg, 2020-07-28:
Update the Main Unit R3 BOM, both in Octopart and in repo.

Andreasdahlberg, 2021-02-07:
Fixed in 90c1dd01fceeb0aa1326f55a0b152b54b442dc94

Closed 2021-02-07.

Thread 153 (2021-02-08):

Incorrect time due to timekeeping register rollover

Andreasdahlberg, 2021-02-08:
**Summary**
Since timekeeping registers are read one at the time from the RTC, its possible for one register to rollover during the read sequence and cause an invalid time.

This affects both the MCP7951x driver and the DS3234 driver.

**Solution**
Utilize the built in buffers designed to prevent this issue by reading all time registers in one read sequence.

Closed 2021-02-16.

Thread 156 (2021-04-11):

Corrupt sensor statistics

Andreasdahlberg, 2021-04-11:
The sensor statistics sometimes get corrupt after reprogramming the device. Missing pull-up on the RTC CS?

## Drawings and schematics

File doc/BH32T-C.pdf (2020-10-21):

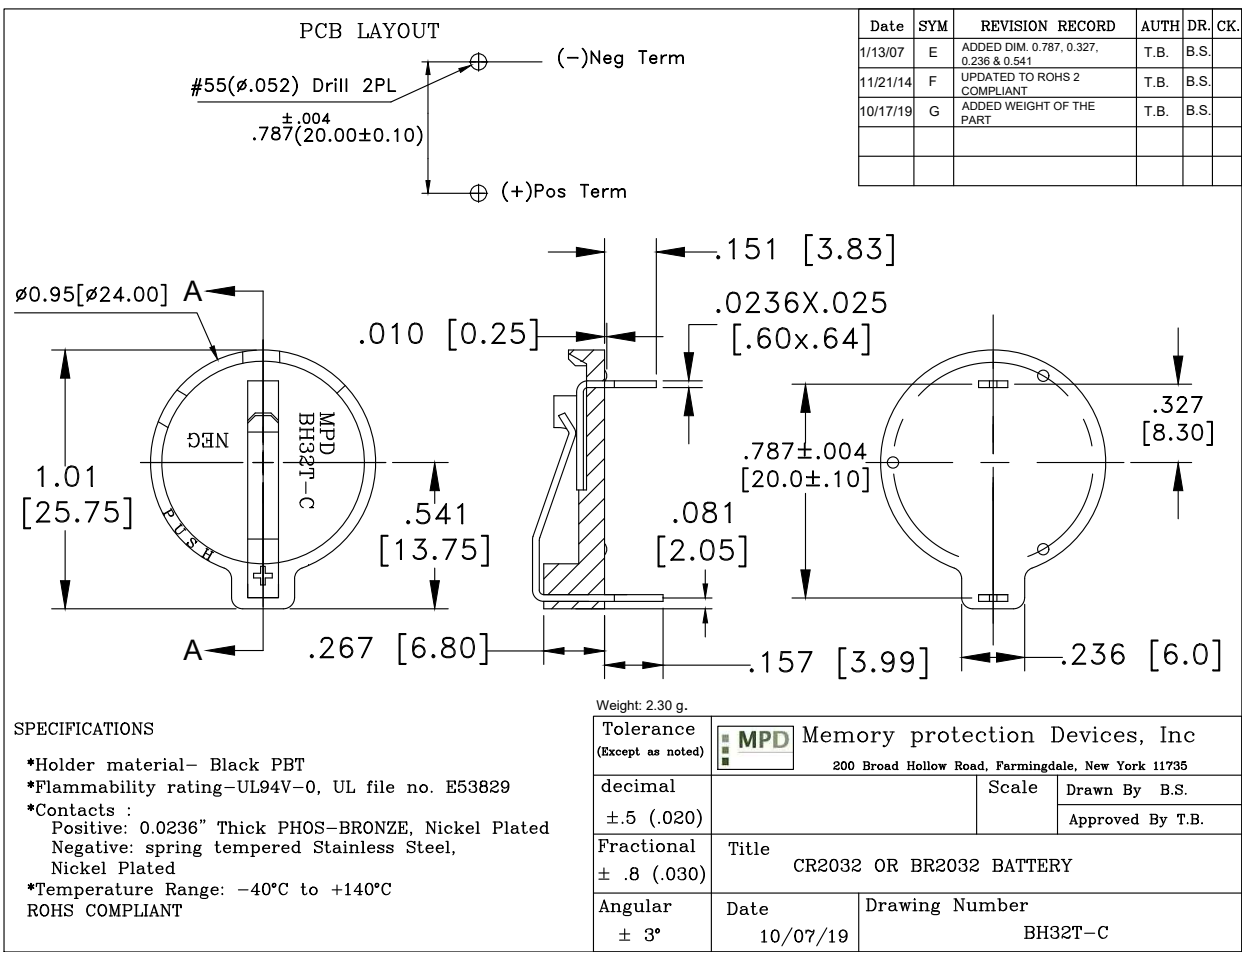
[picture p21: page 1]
ADDED DIM. 0.787, 0.327, 0.236 & 0.541; UPDATED TO ROHS 2 COMPLIANT; B.S. Weight: 2.30 g.; ADDED WEIGHT OF THE PART

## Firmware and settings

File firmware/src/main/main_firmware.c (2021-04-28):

/**
 * @file   main_firmware.c
 * @Author Andreas Dahlberg (andreas.dahlberg90@gmail.com)
 * @date   2021-04-28 (Last edit)
 * @brief  Implementation of main
 */

/*
This file is part of SillyCat firmware.

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
You should have received a copy of the GNU General Public License
along with SillyCat firmware.  If not, see <http://www.gnu.org/licenses/>.
*/

//////////////////////////////////////////////////////////////////////////
//INCLUDES
//////////////////////////////////////////////////////////////////////////

#include "common.h"

#include <avr/io.h>
#include <avr/wdt.h>

#include "libDebug.h"
#include "libSPI.h"
#include "libRFM69.h"
#include "libUI.h"

#include "Board.h"
#include "RTC.h"
#include "ADC.h"
#include "Sensor.h"
#include "Interface.h"
#include "Timer.h"
#include "Transceiver.h"
#include "Com.h"
#include "Nodes.h"
#include "Config.h"
#include "ErrorHandler.h"
#include "PacketHandler.h"
#include "Encoder.h"

#include "driverNTC.h"
#include "driverPEC11.h"

#include "guiRTC.h"
#include "guiSensor.h"
#include "guiNodes.h"

//////////////////////////////////////////////////////////////////////////
//DEFINES
//////////////////////////////////////////////////////////////////////////

#define LOW_STACK_LIMIT 100 // ~5% left of total memory

//////////////////////////////////////////////////////////////////////////
//TYPE DEFINITIONS
//////////////////////////////////////////////////////////////////////////

struct module_t
{
    struct node_t nodes[3];
    uint32_t memory_check_timer;
    bool memory_low_flag;
};

//////////////////////////////////////////////////////////////////////////
//VARIABLES
//////////////////////////////////////////////////////////////////////////

static struct module_t module;

//////////////////////////////////////////////////////////////////////////
//LOCAL FUNCTION PROTOTYPES
//////////////////////////////////////////////////////////////////////////

void CheckMemoryUsage(void);
void assert_fail_handler(const char *file_p, int line_number, const char *expression_p);
void handle_corrupt_config(void);

//////////////////////////////////////////////////////////////////////////
//FUNCTIONS
//////////////////////////////////////////////////////////////////////////

int main(void)
{
#ifdef DEBUG_ENABLE
    uint8_t mcu_status = MCUSR;
    MCUSR = 0;
#endif

    wdt_disable();

    Board_Init();
    libDebug_Init();
    INFO("Main unit started");
    INFO("Last reset: 0x%02X", mcu_status);
    ErrorHandler_Init();
    ErrorHandler_SetAssertFailHandler(assert_fail_handler);
    ADC_Init();
    Timer_Init();
    libSPI_Init(1);
    RTC_Init();
    Sensor_Init();
    driverNTC_Init();

    Interface_Init();
    if (!Config_Load())
    {
        handle_corrupt_config();
    }
    Transceiver_Init();
    Com_Init();
    Encoder_Init();
    //NOTE: The first gui init called will be the root view.
    guiRTC_Init();
    guiSensor_Init();
    guiNodes_Init();
    Nodes_Init();

    Sensor_Register(driverNTC_GetSensor(0));
    Sensor_Register(driverNTC_GetSensor(1));

    for (size_t i = 0; i < ElementsIn(module.nodes); ++i)
    {
        Node_Init(&module.nodes[i], i + 128);
        Nodes_Add(&module.nodes[i]);
    }

    Com_SetPacketHandler(PacketHandler_HandleReadingPacket, COM_PACKET_TYPE_READING);

    const struct encoder_callbacks_t encoder_callbacks =
    {
        .right = Interface_NextView,
        .left = Interface_PreviousView,
        .brief_push = Interface_ActivateView,
        .extended_push = Interface_Action
    };
    Encoder_SetCallbacks(&encoder_callbacks);

    INFO("Start up done");
    DEBUG("Device address: 0x%02X\r\n", Config_GetAddress());

    module.memory_check_timer = Timer_GetMilliseconds();

    while (1)
    {
        Encoder_Update();
        Sensor_Update();
        Transceiver_Update();
        Com_Update();
        Interface_Update();
        CheckMemoryUsage();
    }

    CRITICAL("Main loop exit");
    Board_SoftReset();
}

void CheckMemoryUsage(void)
{
    const uint32_t check_interval = 1000;

    if (Timer_TimeDifference(module.memory_check_timer) > check_interval)
    {
        const uint16_t unused_memory = Board_StackCount();
        DEBUG("Unused memory: %u", unused_memory);

        if (!module.memory_low_flag && unused_memory < LOW_STACK_LIMIT)
        {
            ErrorHandler_LogError(LOW_STACK, unused_memory);
            module.memory_low_flag = true;
            WARNING("Low memory: %u", unused_memory);
        }

        sc_assert(unused_memory > 0);
        module.memory_check_timer = Timer_GetMilliseconds();
    }
}

void assert_fail_handler(const char *file_p, int line_number, const char *expression_p)
{
    UNUSED(expression_p);
    ErrorHandler_LogError(ASSFAIL, 0);

    const char *file_name = strrchr_P(file_p, '/');
    libUI_Print("Assert: %i", 2, UI_DOUBLE_ROW_FIRST, line_number);
    libUI_Print_P(file_name, 2, UI_DOUBLE_ROW_SECOND);
    libUI_Update();
}

void handle_corrupt_config(void)
{
    CRITICAL("Corrupt device configuration");
    ErrorHandler_LogError(CORRUPT_CONFIG, 0);

    libUI_Print("Corrupt config", 0, UI_DOUBLE_ROW_FIRST);
    libUI_Print("V:0x%02X, E:0x%02X", 0, UI_DOUBLE_ROW_SECOND, Config_GetVersion(), CORRUPT_CONFIG);
    libUI_Update();

    ErrorHandler_PointOfNoReturn();
}

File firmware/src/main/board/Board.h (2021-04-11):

/**
 * @file   Board.h
 * @Author Andreas Dahlberg (andreas.dahlberg90@gmail.com)
 * @date   2021-04-11 (Last edit)
 * @brief  Board support package for the main unit.
 */

/*
This file is part of SillyCat firmware.

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
You should have received a copy of the GNU General Public License
along with SillyCat firmware.  If not, see <http://www.gnu.org/licenses/>.
*/

#ifndef BOARD_H_
#define BOARD_H_

//////////////////////////////////////////////////////////////////////////
//INCLUDES
//////////////////////////////////////////////////////////////////////////

#include "commonBoard.h"

//////////////////////////////////////////////////////////////////////////
//DEFINES
//////////////////////////////////////////////////////////////////////////

#define RTC_SPI_DDR     DDRB
#define RTC_SPI_PORT    PORTB
#define RTC_SPI_SS      DDB2
#define RTC_SPI_MODE    1

#define RTC_EXTERNAL_BATTERY true

#define RFM69_SPI_DDR   DDRB
#define RFM69_SPI_PORT  PORTB
#define RFM69_SPI_SS    DDB6
#define RFM69_SPI_MODE  0

#define RFM69_RESET_DDR     DDRC
#define RFM69_RESET_PORT    PORTC
#define RFM69_RESET_PIN     DDC0

#define PEC11_DDR           DDRB
#define PEC11_PINR          PINB
#define PEC11_PORT          PORTB
#define PEC11_DATA_PIN      DDB0
#define PEC11_LATCH_PIN     DDB1
#define PEC11_BUTTON_PIN    DDB7

#define NHD223_DATA_DDR        DDRD
#define NHD223_DATA_PORT       PORTD
#define NHD223_CTRL_DDR        DDRC
#define NHD223_CTRL_PORT       PORTC
#define NHD223_ENABLE_PIN      DDC1
#define NHD223_RESET_PIN       DDC2
#define NHD223_READWRITE_PIN   DDC3
#define NHD223_REGSELECT_PIN   DDC4
#define NHD223_CHIPSELECT_PIN  DDC5

//////////////////////////////////////////////////////////////////////////
//TYPE DEFINITIONS
//////////////////////////////////////////////////////////////////////////

//////////////////////////////////////////////////////////////////////////
//FUNCTION PROTOTYPES
//////////////////////////////////////////////////////////////////////////

/**
 * Initialize low level board hardware.
 */
void Board_Init(void);

/**
 * Initialize the pins required for the PEC11 rotary encoder.
 */
void Board_PEC11_Init(void);

/**
 * Initialize the pins required for the NHD223 OLED display.
 */
void Board_NHD223_Init(void);

void Board_NHD223_SetDataPinsAsOutputs(void);
void Board_NHD223_SetDataPinsAsInputs(void);
void Board_NHD223_SetDataPins(uint8_t data);
void Board_NHD223_SetRegSelectLow(void);
void Board_NHD223_SetRegSelectHigh(void);
void Board_NHD223_SetEnableLow(void);
void Board_NHD223_SetEnableHigh(void);
void Board_NHD223_SetResetLow(void);
void Board_NHD223_SetResetHigh(void);
void Board_NHD223_SetChipSelectLow(void);
void Board_NHD223_SetChipSelectHigh(void);
void Board_NHD223_SetReadWriteLow(void);
void Board_NHD223_SetReadWriteHigh(void);

#endif

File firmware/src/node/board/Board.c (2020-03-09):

/**
 * @file   Board.c
 * @Author Andreas Dahlberg (andreas.dahlberg90@gmail.com)
 * @date   2020-01-22 (Last edit)
 * @brief  Board support package for the node unit.
 */

/*
This file is part of SillyCat firmware.

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
You should have received a copy of the GNU General Public License
along with SillyCat firmware.  If not, see <http://www.gnu.org/licenses/>.
*/

//////////////////////////////////////////////////////////////////////////
//INCLUDES
//////////////////////////////////////////////////////////////////////////

#include "common.h"
#include <avr/io.h>
#include "libSPI.h"
#include "Board.h"

//////////////////////////////////////////////////////////////////////////
//DEFINES
//////////////////////////////////////////////////////////////////////////

#define RTC_SPI_DDR     DDRD
#define RTC_SPI_PORT    PORTD
#define RTC_SPI_MFP     DD3
#define RTC_SPI_SS      DDD4
#define RTC_SPI_MODE 0

#define RFM69_SPI_DDR   DDRB
#define RFM69_SPI_PORT  PORTB
#define RFM69_SPI_SS    DDB2
#define RFM69_SPI_MODE  0

#define RFM69_RESET_DDR     DDRC
#define RFM69_RESET_PORT    PORTC
#define RFM69_RESET_PIN     DDC0

#define RFM69_IO_DDR    DDRC
#define RFM69_IO_PIN    DDC2

//////////////////////////////////////////////////////////////////////////
//TYPE DEFINITIONS
//////////////////////////////////////////////////////////////////////////

//////////////////////////////////////////////////////////////////////////
//LOCAL FUNCTION PROTOTYPES
//////////////////////////////////////////////////////////////////////////

static inline void SetRFM69ResetAsOutput(void);
static inline void SetRFM69ResetAsInput(void);
static inline void SetRFM69ResetHigh(void);
static inline void SetRFM69ResetLow(void);
static inline void SetRFM69IOAsInput(void);

//////////////////////////////////////////////////////////////////////////
//VARIABLES
//////////////////////////////////////////////////////////////////////////

//////////////////////////////////////////////////////////////////////////
//INTERUPT SERVICE ROUTINES
//////////////////////////////////////////////////////////////////////////

//////////////////////////////////////////////////////////////////////////
//FUNCTIONS
//////////////////////////////////////////////////////////////////////////

void Board_Init(void)
{
    Board_RTC_Init();
    Board_RFM69_Init();
}

void Board_RTC_Init(void)
{
    /* Set SS as output and pull high to release device. */
    RTC_SPI_DDR |= (1 << RTC_SPI_SS);
    RTC_SPI_PORT |= (1 << RTC_SPI_SS);
}

void Board_RTC_SPIPreCallback(void)
{
    libSPI_SetMode(RTC_SPI_MODE);
    RTC_SPI_PORT &= ~(1 << RTC_SPI_SS);
}

void Board_RTC_SPIPostCallback(void)
{
    RTC_SPI_PORT |= (1 << RTC_SPI_SS);
}

void Board_RFM69_Init(void)
{
    /* Set SS as output and pull high to release device. */
    RFM69_SPI_DDR |= (1 << RFM69_SPI_SS);
    RFM69_SPI_PORT |= (1 << RFM69_SPI_SS);

    SetRFM69ResetAsInput();
    SetRFM69ResetLow();

    SetRFM69IOAsInput();
}

void Board_RFM69_SPIPreCallback(void)
{
    libSPI_SetMode(RFM69_SPI_MODE);
    RFM69_SPI_PORT &= ~(1 << RFM69_SPI_SS);
}

void Board_RFM69_SPIPostCallback(void)
{
    RFM69_SPI_PORT |= (1 << RFM69_SPI_SS);
}

void Board_RFM69_PullReset(void)
{
    SetRFM69ResetHigh();
    SetRFM69ResetAsOutput();
}

void Board_RFM69_ReleaseReset(void)
{
    SetRFM69ResetAsInput();
    SetRFM69ResetLow();
}

//////////////////////////////////////////////////////////////////////////
//LOCAL FUNCTIONS
//////////////////////////////////////////////////////////////////////////

static inline void SetRFM69ResetAsOutput(void)
{
    RFM69_RESET_DDR |= (1 << RFM69_RESET_PIN);
}

static inline void SetRFM69ResetAsInput(void)
{
    RFM69_RESET_DDR &= ~(1 << RFM69_RESET_PIN);
}

static inline void SetRFM69ResetHigh(void)
{
    RFM69_RESET_PORT |= (1 << RFM69_RESET_PIN);
}

static inline void SetRFM69ResetLow(void)
{
    RFM69_RESET_PORT &= ~(1 << RFM69_RESET_PIN);
}

static inline void SetRFM69IOAsInput(void)
{
    RFM69_IO_DDR &= ~(1 << RFM69_IO_PIN);
}

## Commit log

2014-09-03 Added logo
    Added logo files, both a pretty on and one monochrome for the pcb
    silkskreen
2014-09-03 Created radio block
    Created block for the radio circuit. Solved task #5.
2014-09-03 Voltage regulator done
    Created and approved schematic for the voltage regulator. Solved task #1
    and #2.
2014-09-05 Added power block
    Added schematic for a power block with both the charger and regulator
    circuit.
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2014-09-06 Integrated power block
    Added the power block to the remote node schematic and connected all
    control signals.
2014-09-06 Integrated RTC block
    Added the RTC block to the remote node schematic.
2014-09-06 Removed broken files
    Some assemblys was broken because of invalid paths.
    [battery_holder_2xAA.SLDASM, node_assembly.SLDASM, parts_to_3d_print.SLDASM]
2014-09-07 Removed reset pull-up
    The reset line had two pull up resistors so one of them was removed.
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2014-09-10 Created lower part of casing
    Created a 3D-model for the lower part of the node casing.
    [casing_lower.SLDPRT]
2014-09-10 Created upper part of casing
    Created a 3D-model for the upper part of the node casing.
    [casing_upper.SLDPRT]
2014-09-11 Started node assembly
    [node_assembly.SLDASM]
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2014-09-12 Changed footprint on U5
    Changed the footprint on the thermistor U5 to a custom smd connector.
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2014-09-12 Added 3D-model for USB connector
    [micro USB.SLDASM, micro usb.SLDPRT, micro usb02.SLDPRT]
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2014-09-15 Fixed missing IO connection
    The connection between the radio IO and the microprocessor was missing,
    this is now fixed both in the schematic and the pcb layout.
2014-09-16 Changed footprint on LTC4060
    Changed the footprint on the LTC4060 IC from an TSSOP-16 with exposed
    pad to TSSOP-16 without exposed pad.
2014-09-16 Added pull up to charging signal
    Added a 10K pull up resistor to the charging signal from the battery
    charger.
2014-09-17 Removed pull-ups from charging signals
    Removed both pull-ups from the charging signals since the pulled to 5V
    and the maximum voltage for the input pins is 3.8V. The internal
    pull-ups will be used instead.
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2014-09-18 Done with the first pcb layout
    The pcb layout is all done and passed all automatic checks.
    [remote_node - Board Outline.gbr, remote_node - Copper Bottom.gbr, remote_node - Copper Top-Copper Bottom.drl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]
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2014-09-28 Added DHT22 3D-model
    Added a 3D-model for the DHT22-sensor.
    [dht11_body.SLDPRT, dht11_pcb.SLDPRT, dht_assembly.SLDASM]
2014-09-28 Added 3D-model of PCB-assembly
    Added a 3D-model of the PCB with all its components attached.
    [Antena.SLDASM, SOT-23.SLDPRT, battery_assembly.SLDASM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]
2014-09-29 File cleanup
    Removed unused 3D-models and renamed the pcb-model.
    [board.SLDPRT, casing.SLDPRT, pcb.SLDPRT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]
2014-09-29 Casing adjustments
    Added a new end cover for the casing and adjusted some measurements.
    [1206_led_blue.SLDPRT, battery_assembly.SLDASM, casing_3d_printer_ready.SLDASM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]
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2014-09-30 Created STL files
    Created STL files for all exterior parts. These files are used for the
    3D-printing process.
    [casing_3d_printer_casing_upper_140929.STL, casing_3d_printer_end_cover_140929.STL, casing_3d_printer_end_cover_usb_140929.STL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]
2014-09-30 Adapted exterior for 3D-printing
    Did some minor adjustments to the exterior so they are better suited for
    3D-printing.
    [casing_assembly.SLDASM, casing_lower.SLDPRT, end_cover_usb.SLDPRT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]
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2014-10-12 Fixed minor issues and prepared files for production
    [remote_node - Copper Bottom.gbr, remote_node - Copper Top-Copper Bottom.drl, remote_node - Copper Top.gbr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]
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2014-11-09 Fixed pcb errors
    Changed direction of the battery-holder and increased clearance to the
    powerplane.
    [remote_node - Copper Bottom.gbr, remote_node - Copper Top-Copper Bottom.drl, remote_node - Copper Top.gbr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]
2014-11-19 Minor adjustments to exterior
    Fixed some minor problems with part tolerance.
    [casing_3d_printer_ready.SLDASM, casing_assembly.SLDASM, casing_lower.SLDPRT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]
2014-11-19 Updated gerbers
    Updated gerbers for pcb production, fixed battery holder orientation and
    short circuit on charge programing pin.
    [remote_node - Copper Bottom.gbr, remote_node - Copper Top-Copper Bottom.drl, remote_node - Copper Top.gbr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]
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2014-11-23 Fixed SPI write function, seems to work but is still work in progress. Added SPI update to main.
    [libSPI.c]
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2014-11-26 Added function SetActiveSlave(). This is used to prevent other modules to hijack the SPI-bus.
    [libSPI.c]
2014-11-28 Changed structure in the hardware folder. Added basic schematic for the base unit. Added datasheet for the oled-display.
    [remote_node - Board Outline.gbr, remote_node - Copper Bottom.gbr, remote_node - Copper Top-Copper Bottom.drl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]
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2014-12-17 Addded 3d-models for the main unit. Work in progress.
    [NHD_223_OLED_display.SLDPRT, SMA-angled.SLDPRT, TO-220.SLDPRT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]
2014-12-17 Changed name on the node exterior folder.
    [1206_led_blue.SLDPRT, Antena.SLDASM, Battery.SLDPRT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]
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2015-01-11 Replaced FZT949 with 2SB772 with better power dissipation. Started to replace all 1206 footprints with 1206S, work in progress.
2015-02-10 Replaced footprint on the RTC battery holder. Added more vias to ground.
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2015-02-22 Fixed incorrect voltage divider for light and temperature sensors.
2015-02-23 Fixed some minor issues with the silkscreen.
2015-02-23 Added gerber files for the main unit.
    [main_pcb_assembly.SLDASM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]
2015-02-23 Added soldermask to the mounting holes.
    [main_unit - Copper Bottom.gbr, main_unit - Copper Top-Copper Bottom.drl, main_unit - Copper Top.gbr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]
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2015-04-11 Fixed issue with init, entire PORTB register was set.
    [libSPI.c]
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2015-05-17 Fixed incorrect setting for ADC reference voltage.
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2015-07-27 Migrated battery charger schematic to Multisim 14. Increased value of Ctimer to 1100pF, this gives a maximum charge time of 2.5 h. Fixed incorrect footprints for resistors and capacitors. Added some 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
2015-07-27 Migrated power block to Multisim 14. Integrated new charger and regulator block into power block. Fixed incorrect resistor and capacitor footprints.
2015-07-27 Migrated RTC block to Multisim 14. Fixed incorrect footprints. Added detailed part information.
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2015-07-27 Replaced input schottky diode with smaller version.
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2015-08-16 Replace IPS-header with test points for a pogo adapter. Also did this for RX and TX. Fixed incorrect footprint for the RTC crystal.
2015-08-23 Replaced footprint for U4 with wago-2059-303.
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2015-09-05 Removed unused component.
    [cover_plate.SLDPRT]
2015-09-05 Added new heatsink model.
    [heatsink_V5618A.SLDPRT]
2015-09-05 Added new heatsinks to pcb assembly. Files updated to new format(SW 2015).
    [1206_led_blue.SLDPRT, Antena.SLDASM, Battery.SLDPRT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]
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2015-09-05 Added 3D-model of the Wago 2059-303 connector.
    [wago_2059_303.SLDPRT.SLDASM, wago_2059_303_casing.SLDPRT, wago_2059_303_pin.SLDPRT]
2015-09-05 Added 3D-model of a NFC-tag.
    [nfc_tag.SLDPRT]
2015-09-05 Added NFC-tag and Wago connector to the main assembly.
    [node_assembly.SLDASM, pcb_assembly.SLDASM]
2015-09-06 Added DPAK transistor to pcb.
    [DPAK.SLDPRT, node_assembly.SLDASM, pcb_assembly.SLDASM]
2015-09-06 Replaced antenna with new model.
    [Antena.SLDASM, SMA_antenna.SLDPRT, SMA_nut.SLDPRT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]
2015-09-07 Removed unused part. Minor adjustments to casing and pcb.
    [casing_assembly.SLDASM, casing_plug.SLDPRT, end_cover_usb.SLDPRT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]
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2015-09-07 Moved production files to new directory, production_files.
    [casing_casing_upper.STL, casing_end_cover.STL, casing_end_cover_usb.STL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]
2015-09-07 Added new model for the AA-batteries.
    [Battery.SLDPRT, aa_battery.SLDPRT, battery_assembly.SLDASM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]
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2015-09-13 Disabled display when debug is active, VRAM is flushed to UART instead. Fixed some minor compilation warnings. Fixed code styling.
    [libDisplay.c]
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2015-09-17 Fixed issue with missing );
    [libDisplay.c]
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2015-09-20 Fixed potential issue with reading system timer without disabling interrupts.
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2015-10-03 Fixed document format, replaced tabs with spaces and added documentation.
    [libDisplay.c]
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2015-10-03 Fix for #57 in libDS3234. Implemented functions to write and read from battery powered SRAM.
2015-10-03 Fix for #57 in libRFM69. More hardware interface functions implemented.
    [libRFM69.h]
2015-10-03 Replaced tabs with spaces. Added some bit defines.
    [libRFM69.h]
2015-10-04 Fixed issue incorrect temperature conversion.
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2015-10-28 Fixed undefined reference. Added view for sensor information. Fixed code style.
2015-10-29 Implemented push button. Added include guard in header. Fixed minor code style issues.
2015-10-29 Fixed missing function prototype. Added dummy function for libDS3234_GetYear().
2015-11-02 Fixed correct footprint for S25FL164.
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2015-11-05 Replaced all calls to libTimer with Timer calls. Some minor code style fixes.
    [main_firmware.c]
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2015-11-11 Fixed issue with ADIF-bit not cleared after an ADC-conversion. Style fixes.
2015-11-11 Removed old non working code. Renamed some function arguments. Style fixes.
    [libSPI.c]
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2015-11-17 Fixed incorrect condition when checking if PA-mode is valid. Implemented function to enable/disable high power settings. Fixed minor style issues.
    [libRFM69.h]
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2015-12-13 Added AStyle settings.
    [AStyle_settings.cfg]
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2016-01-17 Adjusted low and critical battery volatges. Fixed issue with reading of battery voltage before the ADC was running.
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2016-01-25 Made some variables static. Style fixes.
    [libSPI.c]
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2016-01-31 Added reset of LED timer when changing state.
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2016-02-05 Removed function name from debug on failed asserts to reduced RAM usage. Made temporary fix for broken filename and linenumber prints.
2016-02-07 Fixed issue with false push on start, caused by reading of the ADC before any conversion was done.
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2016-02-13 Fixed incorrect pin-mapping for the 2SB1182.
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2016-02-13 Added BOM.
    [BOM.xlsx]
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2016-03-20 Fixed incorrect footprint for the pogo connector in schematic.
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2016-03-20 Updated production files.
    [BOM.xlsx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]
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2016-05-08 Implemented reset functionality for the RFM69 module. Added better separation to board specific hardware.
    [libRFM69.h]
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2016-05-16 Added missing include, Timer.h Fixed typo.
    [UART.c]
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2016-05-16 Added missing newline in debug print.
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2016-05-17 Added error handler init to main. Fixed issue with error handler in release mode.
    [main_firmware.c]
2016-05-19 Fixed proper reading of the internal mcu temperature. Added temperature calibration. Some code cleaning.
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2016-06-07 Revert "Merge branch 'master' of https://github.com/Andreasdahlberg/sillycat"
    This reverts commit da48c5b9d4959acfcef3f6e66592e0e3958a0d3d, reversing
    changes made to ec312b0b38d0587f132b2add0f00b8f6f8eb1356.
    [node_assembly.SLDASM, pcb_assembly.SLDASM, wago_tool.SLDPRT]
2016-06-18 Replaced Atmel studio based build system with Scons and avrdude.
    [AStyle_settings.cfg, astyle.cfg]
2016-06-18 Fixed case issue in include
2016-06-20 Fixed issue with no debug prints after sleep.
2016-06-20 Fixed broken timeout while waiting for UART TX.
    [UART.c]
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2016-06-29 Fixed broken libRFM69_GetTemperature function.
    [libRFM69.h]
2016-07-03 Fixed issue with no debug prints in some wakeup functions.
2016-07-03 Fixed unused variable warning in libDisplay.
    [libDisplay.c]
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2016-08-28 Implemented functions to set the rx timeouts. Fixed spelling error.
    [libRFM69.h]
2016-09-24 Fixed proper reset of tx and rx packet frames at init.
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2016-10-23 Fixed mismatch between the sensor_data_type in node and main unit.
2017-03-30 Add missing function prototype
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2017-08-17 Fix SPI bus issues
    Replace the 4.7K Ohm resistors in series with the SPI signals with 100 Ohm resistors. This increases the rise times from 680 ns to less then 60 ns.
    Add pull-up resistor on the RFM69 CS pin so the chip does not interfere during programming.
2017-08-17 Fix incorrect init state of the RFM69 CS pin
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2017-08-26 Fix proper sensor view for invalid readings
2017-08-26 Fix issue with temperatures below zero
    [main_firmware.c]
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2018-02-11 Remove function to calculate exponential moving average
    The function was not used and is intended to be replaced by a filter
    module.
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2018-03-08 Add error code for corrupt device configuration
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2018-03-21 Fix issue with displaying invalid sensor statistics
2018-03-26 Use fixed point arithmetic when calculating battery voltage
2018-03-28 Fix overflow in battery voltage calculation
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2018-04-09 Remove error log printing at start
    [main_firmware.c]
2018-04-09 Fix incorrect battery charged icon
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2018-04-11 Fix #97
    Implement battery discharge protection.
2018-04-11 Fix power management module code style
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2018-08-30 Add protection resistor to between VCC and encoder button
    Add a protection resistor connected between VCC and the rotary encoder button to limit the current in case of short circuit in the rotary encoder.
    See #102.
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2018-09-22 Fix inverted push button signal
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2018-09-22 Reset activity timer on init
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2018-10-03 Fix incorrect error code for high MCU temperature errors
    [main_firmware.c]
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2018-10-15 Implement custom assert fail handler
    Remove NDEBUG flag so that asserts are kept in release builds.
    [main_firmware.c]
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2018-10-24 Add missing include of sensor header
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2018-10-24 Reset sample timer at init
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2018-10-26 Add missing include in NTC driver header
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2019-02-18 Remove gerbers
    [main_unit - Board Outline.gbr, main_unit - Copper Bottom.gbr, main_unit - Copper Top-Copper Bottom.drl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]
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2019-02-18 Fix missing footprint
    Fix footprint for the RTC crystal.
2019-02-20 Fix incorrect footprint in radio block
2019-02-20 Swap thermistor pins
    Swap thermistor pins to make the PCB layout easier.
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2019-03-16 [skip ci] Add missing trace
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2019-03-16 [skip ci] Remove soldermask on mounting holes
2019-04-27 Fix sonarcloud issues
2019-04-27 Fix code style in libUART
    [libUART.c]
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2019-06-04 Skip sonar scan for tag triggered builds
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2020-03-09 Replace DS3234 driver with MCP79510
    [Board.c, Board.h, main_firmware.c]
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2020-03-09 Fix incorrect pin defines
    [Board.c]
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2020-03-09 Move soft reset to board module
    [main_firmware.c]
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2020-03-09 Fix sonarcloud warnings in FIFO-module
2020-03-09 Fix sonarcloud warnings in UART-module
    [UART.c]
2020-03-11 Fix sonarcloud warnings
2020-03-11 Fix more sonarcloud warnings
2020-03-11 Fix sonarcloud warning
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2020-04-11 Fix PEC11 init
    This fixes the issue with intermittent encoder signals at startup.
    [Board.c]
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2020-05-01 Fix board specific init of RTC battery
    [Board.h]
2020-05-01 Add missing Board mock
    [Board.h]
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2020-05-19 Change crystal load capacitors
    Part of the fix for #145
2020-05-26 Fix #141
    Replace antenna SMA connector with U.FL.
2020-05-26 Fix #142
    Move the ISP-connector towards the middle
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2020-10-05 Fix sonarcloud code smells
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2021-01-23 Fix hour validation in MCP79510 driver
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2021-01-23 Minor fix in driverMCP79510
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2021-01-23 Fix broken 'driverDS3234_GetTemperature'
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2021-02-07 Fix UART include
    Only include the UART header for debug builds
    [Display.c]
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2021-02-16 Fix broken 12h mode in DS3234 driver
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2021-03-21 Fix reversed NHD2.23 CS signal
    [Board.c]
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2021-04-11 Swap PEC11 data and latch pins
    Swap pins to fix issue with reversed direction on revison 3 hardware.
    [Board.h]
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2021-04-28 Remove high MCU temperature error code
2021-04-28 Log failed asserts to error log
    [main_firmware.c]

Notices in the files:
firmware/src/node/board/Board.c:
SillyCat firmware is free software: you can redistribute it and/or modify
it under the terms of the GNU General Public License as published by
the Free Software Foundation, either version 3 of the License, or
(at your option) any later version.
